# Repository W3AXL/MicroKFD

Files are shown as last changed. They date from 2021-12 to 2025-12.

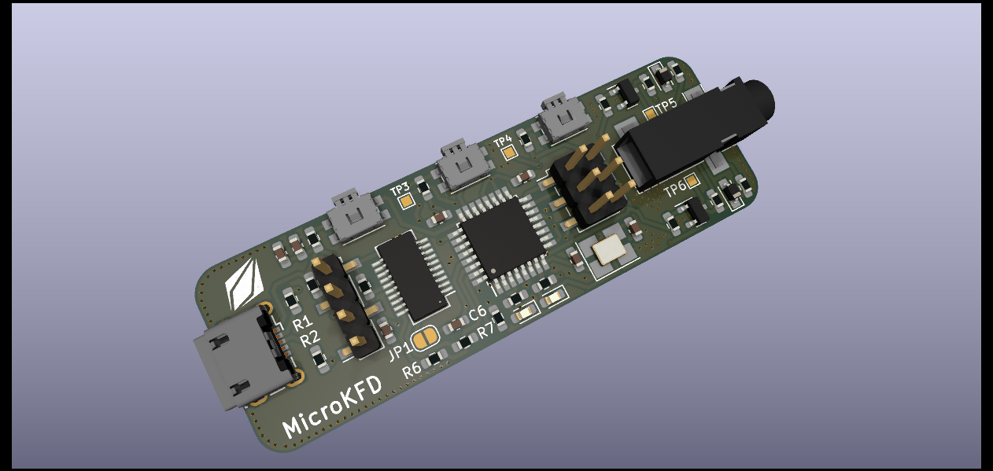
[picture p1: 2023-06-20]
board-revE.png

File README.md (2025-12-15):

The KFDMicro (formerly known as MicroKFD) is a small, compact KFD keyfill device for P25 two-way radios.

Schematics and board layout are available in this repo. The official boards (which provide a small kickback to the original developers) can be purchased at:
https://store.w3axl.com/collections/kfd-keyloading

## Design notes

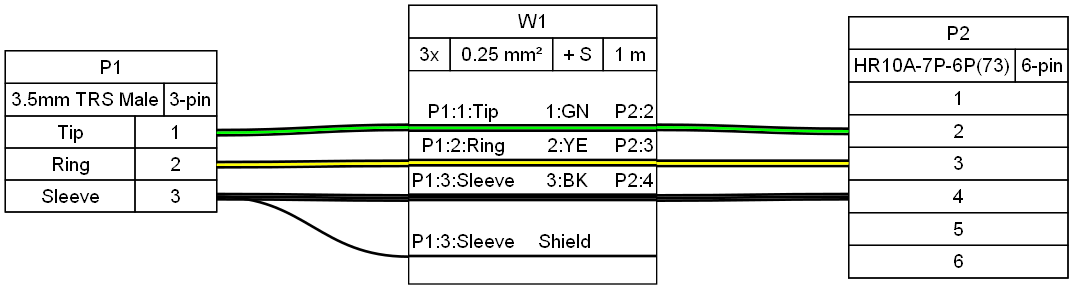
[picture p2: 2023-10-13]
cables/hirose-adapter.png

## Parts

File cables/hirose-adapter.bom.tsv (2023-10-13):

Id | Description | Qty | Unit | Designators
1 | Cable, 3 x 0.25 mm² shielded | 1 | m | W1
2 | Connector, 3.5mm TRS Male, 3 pins | 1 |  | P1
3 | Connector, HR10A-7P-6P(73), 6 pins | 1 |  | P2

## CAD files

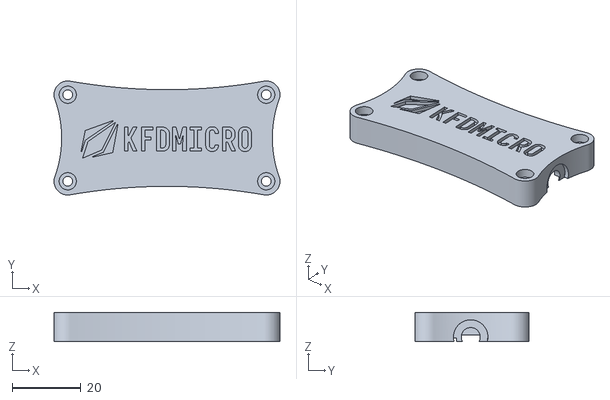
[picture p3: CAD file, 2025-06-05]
enclosure/enclosure-top-revB.stl
65.6 x 33.1 x 8.50

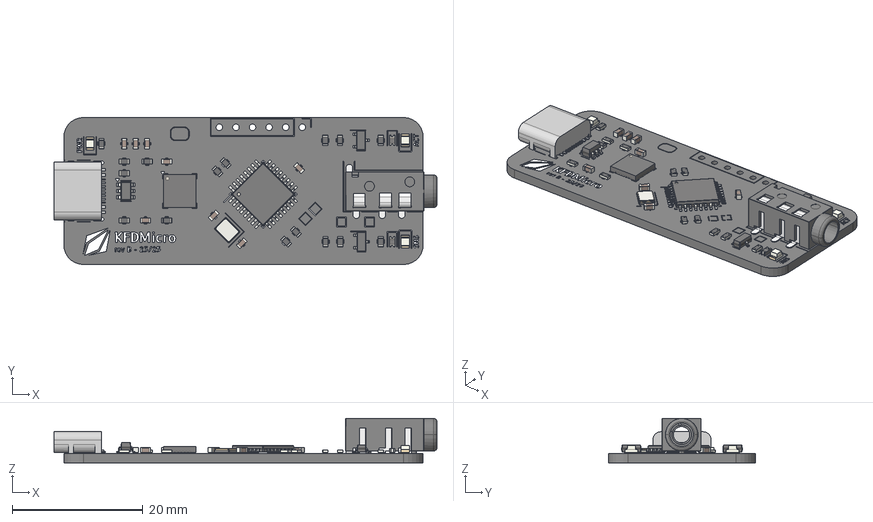
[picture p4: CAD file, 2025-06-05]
microkfd-revB.step
58.6 x 22.5 x 6.92 mm
LED_0805_2012Metric x 3
SOT-23 x 2
C_0603_1608Metric x 8
R_0603_1608Metric x 15
Crystal_SMD_3225-4Pin_3.2x2.5mm
TQFP-32_7x7mm_P0.8mm
HRO TYPE-C-31-M-12
QFN-28-1EP_5x5mm_P0.5mm_EP3.35x3.35mm
D_0603_1608Metric x 2
PJ320A
PJ320D-Pin x 3
PJ320D-Pin-B
SOT-23-6
Fuse_0603_1608Metric
microkfd_silkscreen
microkfd_PCB

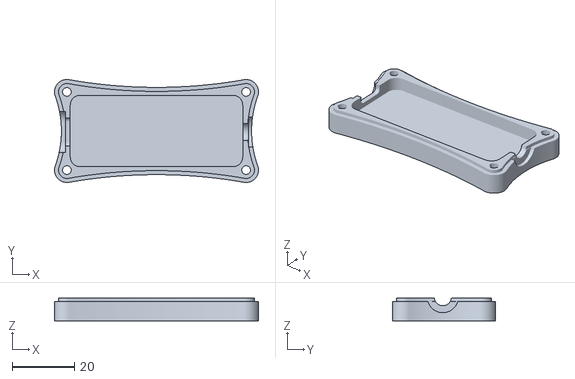
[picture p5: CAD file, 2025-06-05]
enclosure/enclosure-bottom-revB.stl
65.6 x 33.1 x 7.25

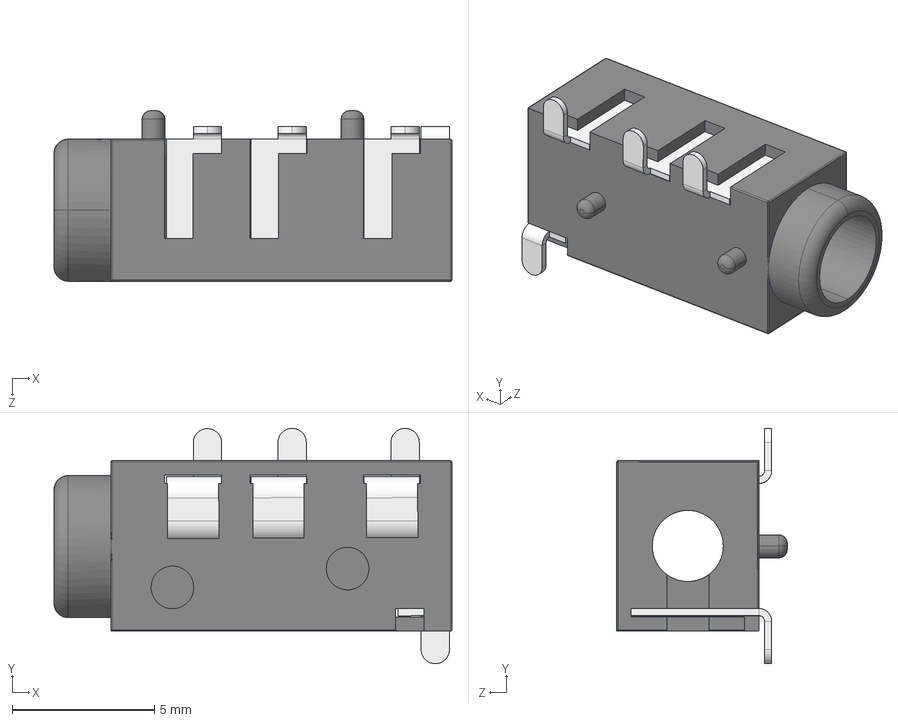
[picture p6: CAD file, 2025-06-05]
PJ320D.STEP
14.0 x 8.28 x 6.00 mm
PJ320A
PJ320D-Pin x 3
PJ320D-Pin-B

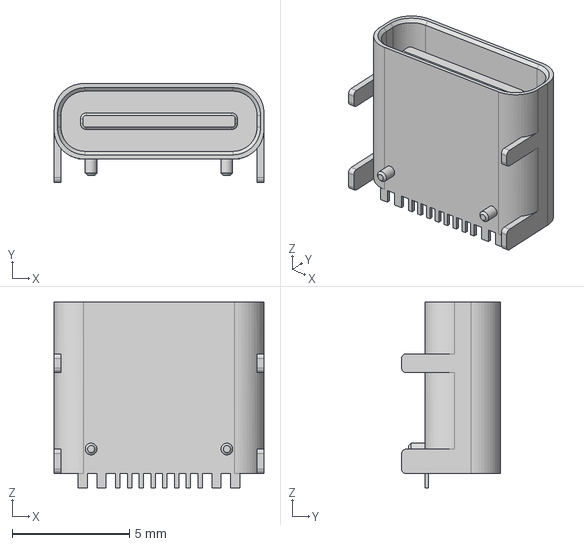
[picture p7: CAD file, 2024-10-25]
HRO TYPE-C-31-M-12.step
8.94 x 4.21 x 7.90 mm

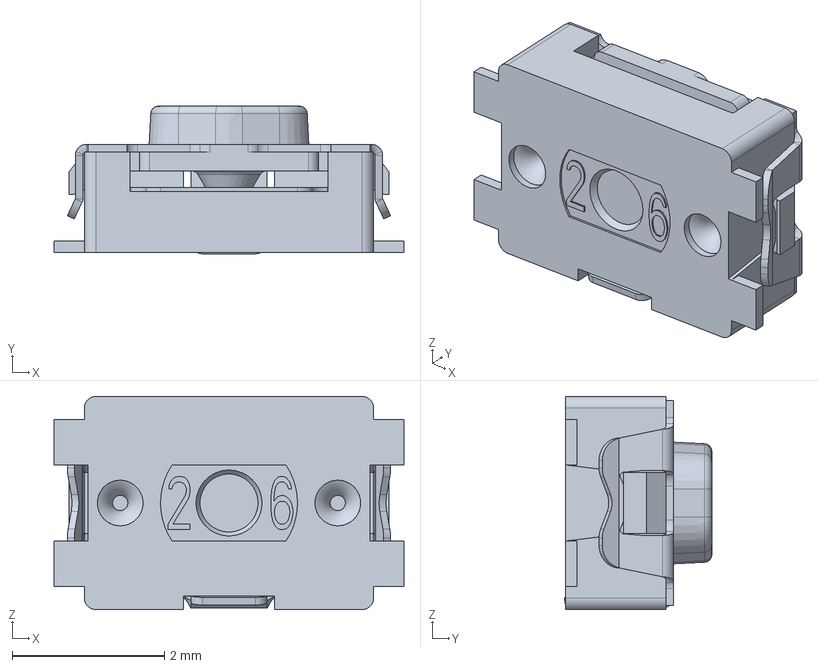
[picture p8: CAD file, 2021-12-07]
KMR211GLFS.stp
4.60 x 1.94 x 2.80 mm

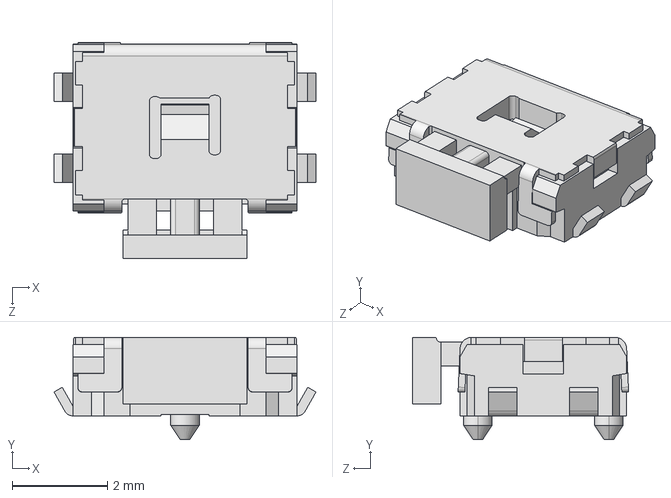
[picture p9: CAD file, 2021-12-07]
EVQPU-MD-02K.STEP
5.50 x 2.15 x 4.54 mm

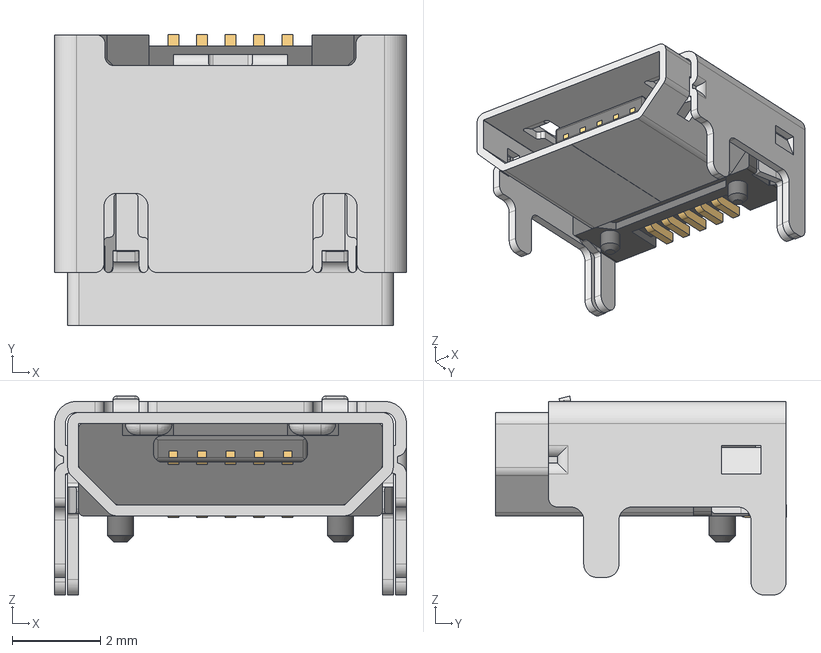
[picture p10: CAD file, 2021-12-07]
629105150521_Download_STP_629105150521_rev1.stp
8.00 x 6.60 x 4.52 mm
629105150521_Pin1 x 4
629105150521_Housing
629105150521_Pin2
629105150521_Shielding
629105150521_Shielding2

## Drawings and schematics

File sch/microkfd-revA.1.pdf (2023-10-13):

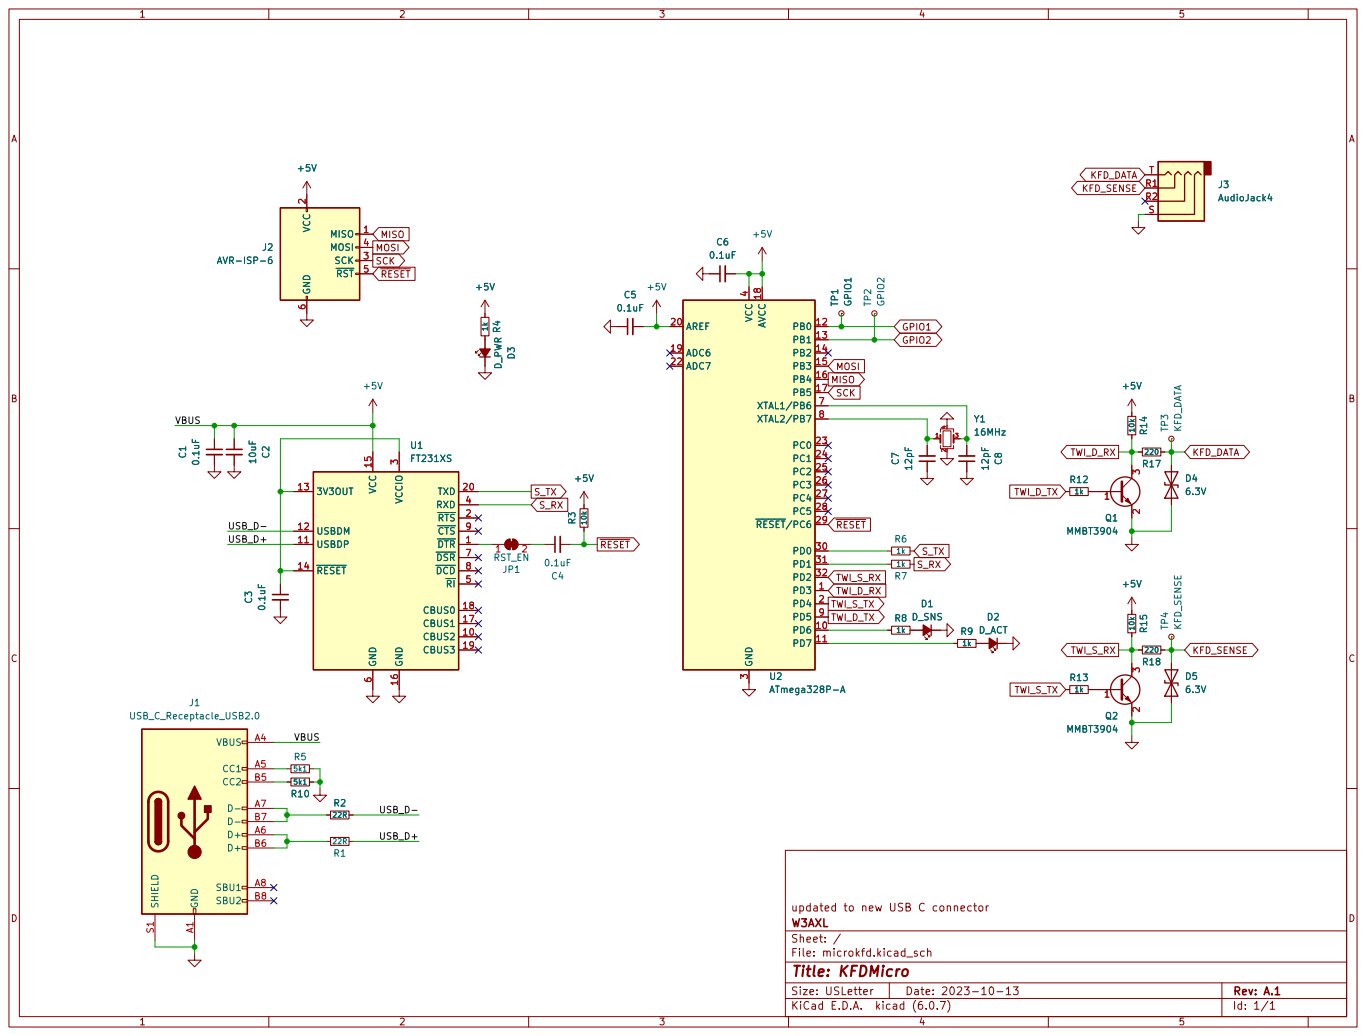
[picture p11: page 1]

2 SCK 3 MOSI 4 ~{RST} 5 GND

2 3 Q1 MMBT3904 PD3 1 PD6 10 PD7 11 PB0 12 PB1 13 PB2 14 PB3 15 PB4 16 PB5 17 AVCC 18 ADC6 19 PD4 2 AREF 20 ADC7 22 PC0 23 PC1 24 PC2 25 PC3 26 PC4 27 PC5 28 ~{RESET}/PC629 GND

updated to new USB C connector
File: microkfd.kicad_sch Sheet: / W3AXL

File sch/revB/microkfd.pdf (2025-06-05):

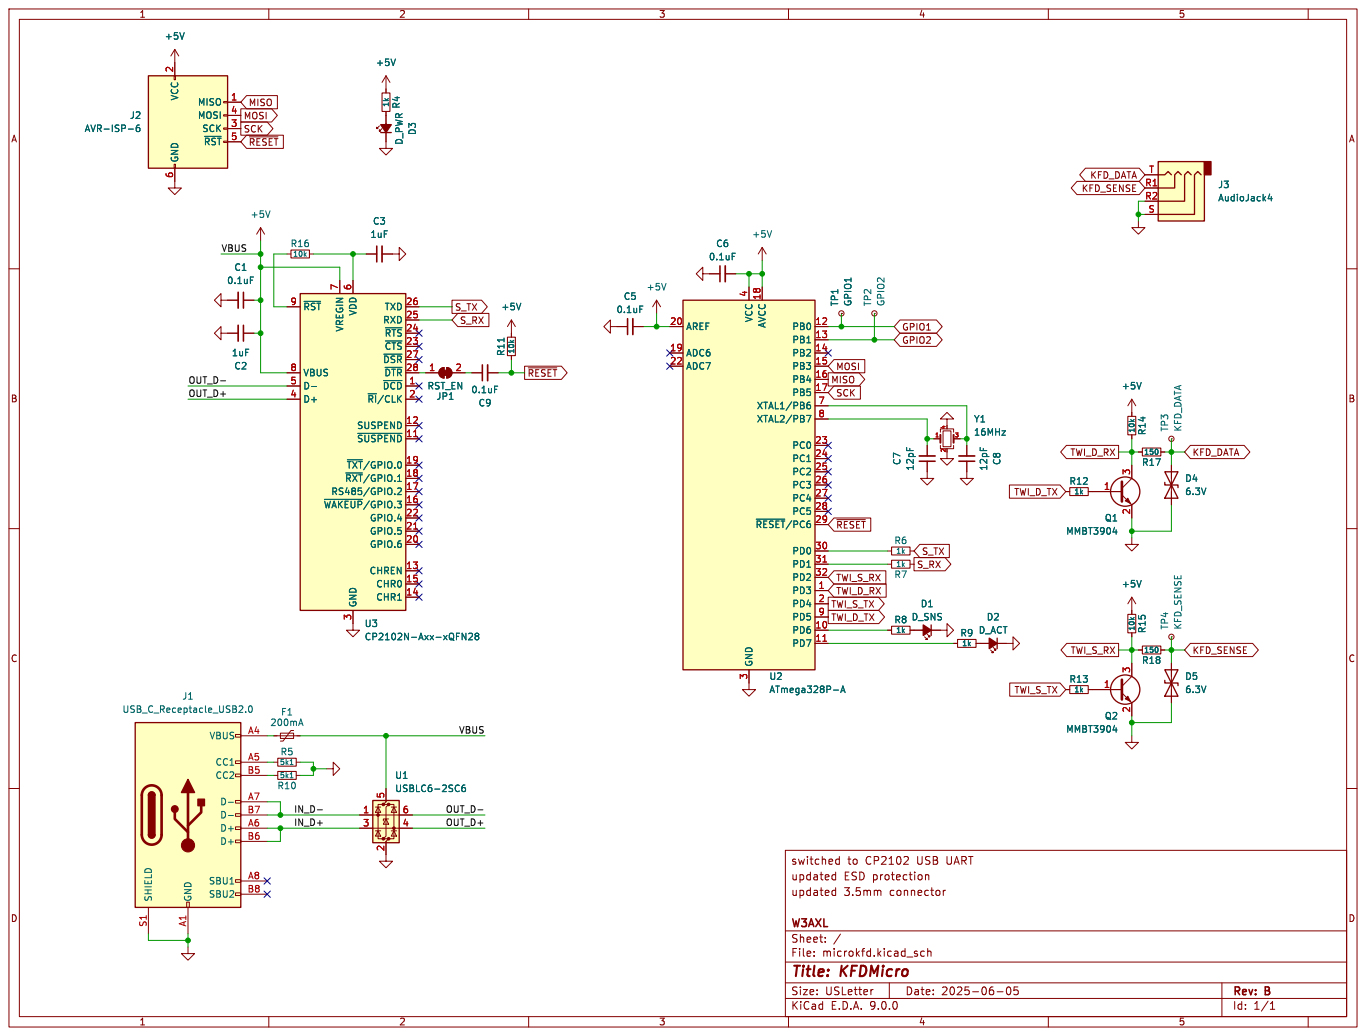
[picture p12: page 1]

6 MISO 1 MOSI 4 SCK 3 ~{RST}5 +5V 1k R4 C3

6 MISO 1 MOSI 4 SCK 3 ~{RST}5

3 TXD 26 RXD 25 ~{RTS} 24 ~{CTS} 23 ~{DSR} 27 ~{DTR} 28 ~{DCD}1 ~{RI}/CLK2 SUSPEND 12 ~{SUSPEND}11 ~{TXT}/GPIO.019 ~{RXT}/GPIO.118 RS485/GPIO.2 17 ~{WAKEUP}/GPIO.316 GPIO.4 22 GPIO.5 21 GPIO.6 20 CHREN 13 CHR0 15 CHR1 14 U3 CP2102N-Axx-xQFN28 D2 D_ACT D3 D_PWR

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

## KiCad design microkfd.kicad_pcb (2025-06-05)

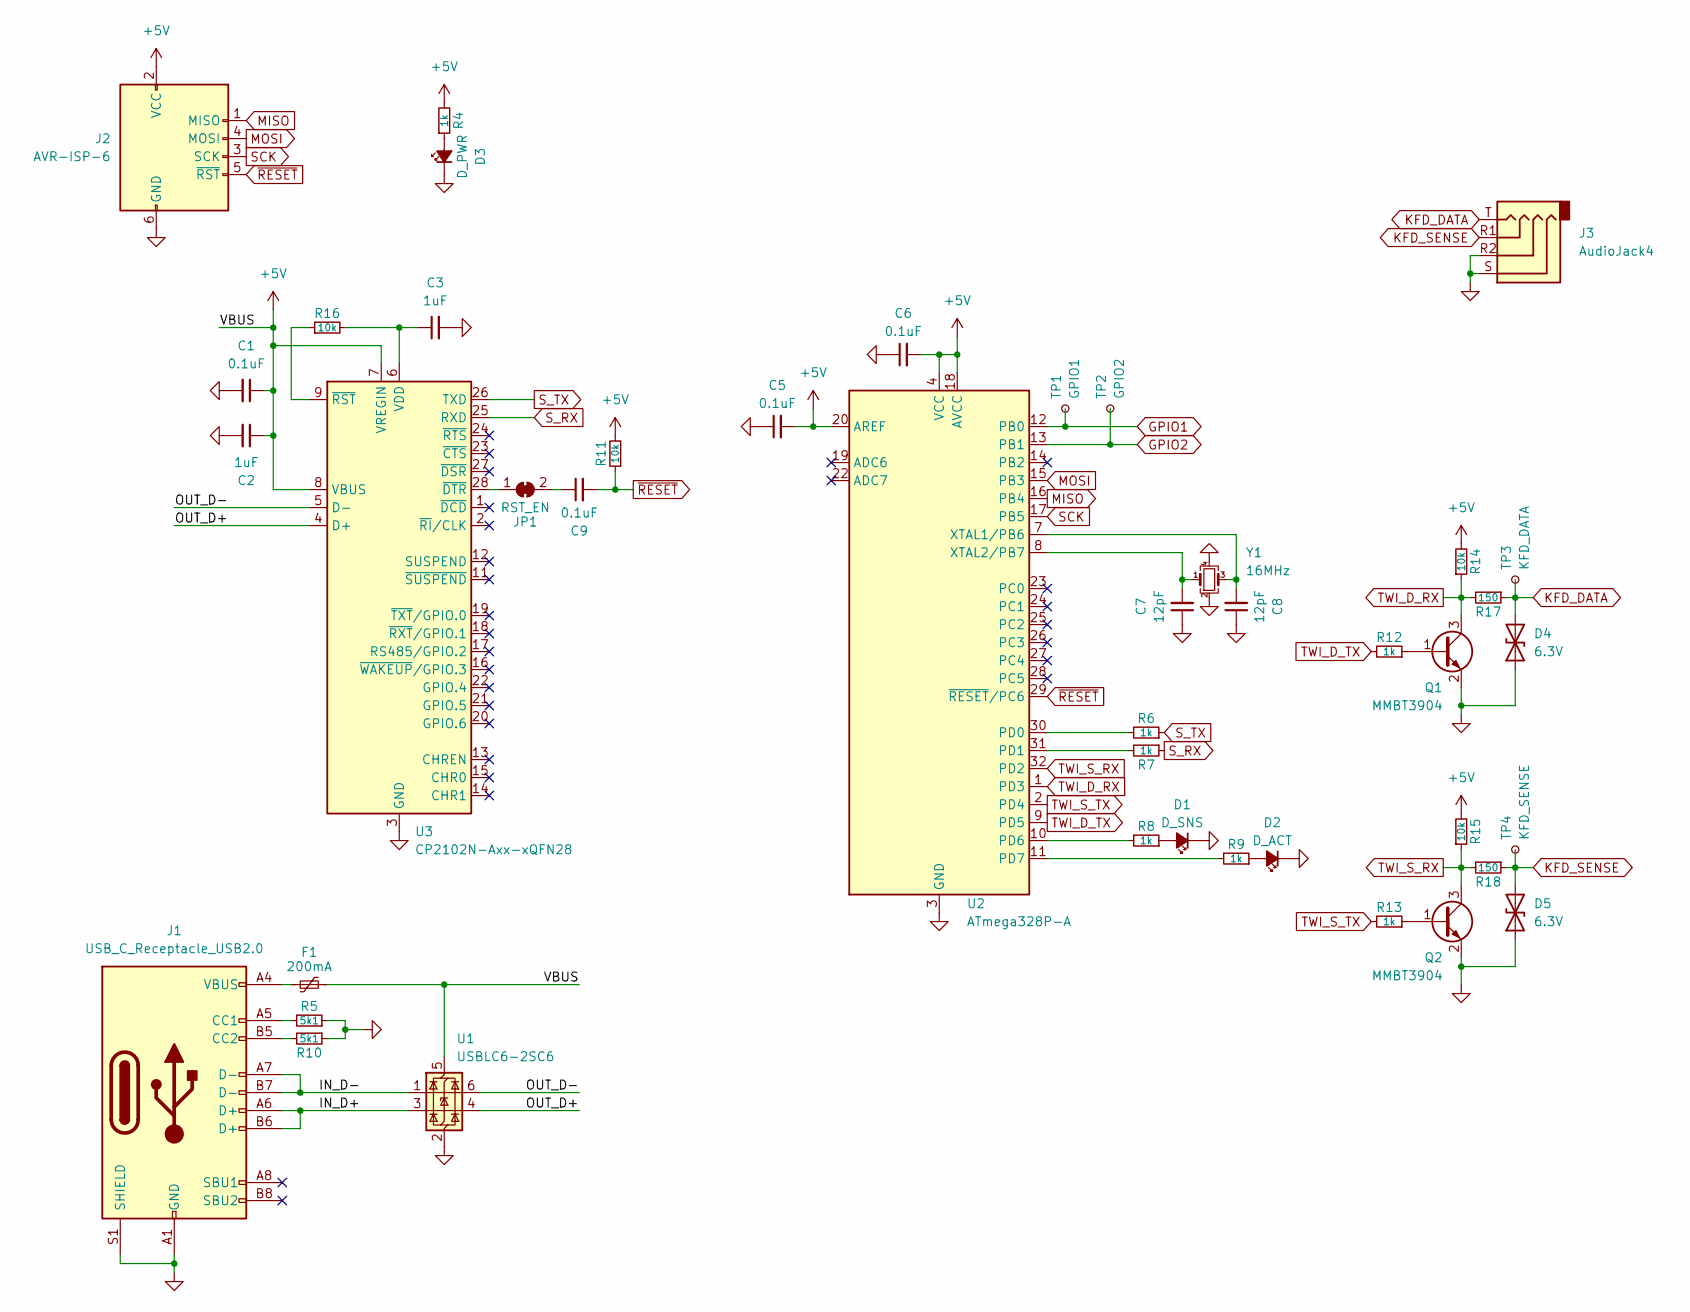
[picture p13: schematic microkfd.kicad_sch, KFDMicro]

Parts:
C1, C5, C6, C9: 0.1uF; C_0603_1608Metric; LCSC C28233
C2, C3: 1uF; C_0603_1608Metric; LCSC C15850
C7, C8: 12pF; C_0603_1608Metric; LCSC C1792
D1: D_SNS; LED_0805_2012Metric; LCSC C84256
D2: D_ACT; LED_0805_2012Metric; LCSC C84256
D3: D_PWR; LED_0805_2012Metric; LCSC C2297
D4, D5: 6.3V; D_0603_1608Metric; LCSC C85200
F1: 200mA; Fuse_0603_1608Metric
J1: USB_C_Receptacle_USB2.0; USB_C_Receptacle_HRO_TYPE-C-31-M-12; LCSC C2874595
J2: AVR-ISP-6; PinHeader_1x06_P2.54mm_Vertical
J3: AudioJack4; Jack_3.5mm_KoreanHropartsElec_PJ-320D-4A_Horizontal; LCSC C707216
JP1: RST_EN; SolderJumper-2_P1.3mm_Bridged_RoundedPad1.0x1.5mm
Q1, Q2: MMBT3904; SOT-23; LCSC C20526
R4, R6, R7, R8, R9, R12, R13: 1k; R_0603_1608Metric; LCSC C17513
R5, R10: 5k1; R_0603_1608Metric; LCSC C27834
R11, R14, R15, R16: 10k; R_0603_1608Metric; LCSC C17414
R17, R18: 150; R_0603_1608Metric; LCSC C17557
TP1: GPIO1; TestPoint_Pad_1.0x1.0mm
TP2: GPIO2; TestPoint_Pad_1.0x1.0mm
TP3: KFD_DATA; TestPoint_Pad_1.0x1.0mm
TP4: KFD_SENSE; TestPoint_Pad_1.0x1.0mm
U1: USBLC6-2SC6; SOT-23-6
U2: ATmega328P-A; TQFP-32_7x7mm_P0.8mm; LCSC C14877
U3: CP2102N-Axx-xQFN28; QFN-28-1EP_5x5mm_P0.5mm_EP3.35x3.35mm
Y1: 16MHz; Crystal_SMD_3225-4Pin_3.2x2.5mm; LCSC C2149025

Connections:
+5V: C1.1, C2.1, C5.2, C6.2, F1.2, J2.2 (VCC), R4.2, R11.2, R14.2, R15.2, U1.5 (VBUS), U2.4 (VCC), U2.6 (VCC), U2.18 (AVCC), U2.20 (AREF), U3.7 (VREGIN), U3.8 (VBUS)
/IN_D+: J1.A6 (D+), J1.B6 (D+), U1.3 (I/O2)
/IN_D-: J1.A7 (D-), J1.B7 (D-), U1.1 (I/O1)
/OUT_D+: U1.4 (I/O2), U3.4 (D+)
/OUT_D-: U1.6 (I/O1), U3.5 (D-)
GND: C1.2, C2.2, C3.2, C5.1, C6.1, C7.1, C8.1, D1.1 (K), D2.1 (K), D3.1 (K), D4.1 (A1), D5.1 (A1), J1.A1 (GND), J1.A12 (GND), J1.B1 (GND), J1.B12 (GND), J1.S1 (SHIELD), J2.6 (GND), J3.R2, J3.S, Q1.2 (E), Q2.2 (E), R5.1, R10.1, U1.2 (GND), U2.3 (GND), U2.5 (GND), U2.21 (GND), U3.3 (GND), U3.29 (GND), Y1.2, Y1.4
GPIO1: TP1.1, U2.12 (PB0)
GPIO2: TP2.1, U2.13 (PB1)
KFD_DATA: D4.2 (A2), J3.T, R17.1, TP3.1
KFD_SENSE: D5.2 (A2), J3.R1, R18.1, TP4.1
MISO: J2.1 (MISO), U2.16 (PB4)
MOSI: J2.4 (MOSI), U2.15 (PB3)
unnamed: D1.2 (A), R8.1
unnamed: D2.2 (A), R9.1
unnamed: D3.2 (A), R4.1
unnamed: F1.1, J1.A4 (VBUS), J1.A9 (VBUS), J1.B4 (VBUS), J1.B9 (VBUS)
unnamed: J1.A5 (CC1), R5.2
unnamed: J1.B5 (CC2), R10.2
unnamed: JP1.1 (A), U3.28 (~DTR)
unnamed: C9.1, JP1.2 (B)
unnamed: Q1.1 (B), R12.1
unnamed: Q2.1 (B), R13.1
unnamed: R6.2, U2.30 (PD0)
unnamed: R7.2, U2.31 (PD1)
unnamed: R8.2, U2.10 (PD6)
unnamed: R9.2, U2.11 (PD7)
unnamed: C8.2, U2.7 (XTAL1/PB6), Y1.3
unnamed: C7.2, U2.8 (XTAL2/PB7), Y1.1
unnamed: C3.1, R16.2, U3.6 (VDD)
unnamed: R16.1, U3.9 (~RST)
SCK: J2.3 (SCK), U2.17 (PB5)
S_RX: R7.1, U3.25 (RXD)
S_TX: R6.1, U3.26 (TXD)
TWI_D_RX: Q1.3 (C), R14.1, R17.2, U2.1 (PD3)
TWI_D_TX: R12.2, U2.9 (PD5)
TWI_S_RX: Q2.3 (C), R15.1, R18.2, U2.32 (PD2)
TWI_S_TX: R13.2, U2.2 (PD4)
~RESET: C9.2, J2.5 (~RST), R11.1, U2.29 (~RESET/PC6)

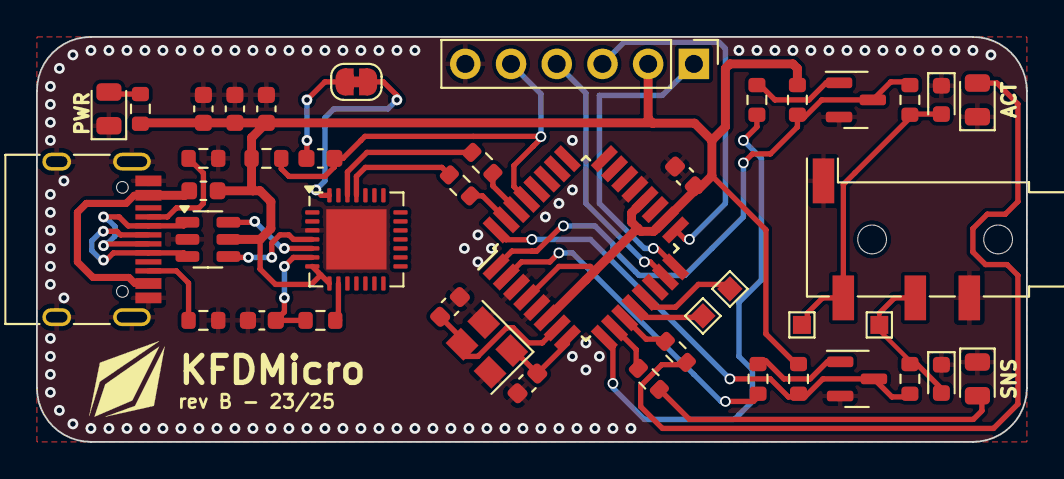
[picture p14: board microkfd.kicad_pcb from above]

Board: 2 copper layers, 55.0 x 22.5 mm, 43 parts (0 on the bottom side), 38 nets.

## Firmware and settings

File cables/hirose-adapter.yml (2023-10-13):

connectors:
  P1:
    pincount: 3
    pinlabels: [Tip, Ring, Sleeve]
    type: 3.5mm TRS Male
  P2:
    pincount: 6
    type: HR10A-7P-6P(73)
  
cables:
  W1:
    wirecount: 3
    length: 1
    shield: true
    gauge: 0.25 mm2
    colors: [GN, YE, BK]

connections:
  - 
    - P1: 3
    - W1: s
  -
    - P1: [1-3]
    - W1: [1-3]
    - P2: [2-4]

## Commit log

2021-12-06 Initial project commit
    [microkfd.kicad_pcb, microkfd.sch]
2021-12-07 rev A design done
    [629105150521_Download_STP_629105150521_rev1.stp, CUI_DEVICES_SJ-3523-SMT-TR.step, EVQPU-MD-02K.STEP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]
2021-12-07 added gerbers
2022-01-08 cleanups and updates
    - switched to Kicad 6.0
    - removed Kicad 5.x files
    - switched to 32u4RC due to availability
    [microkfd-B_Cu.gbr, microkfd-B_Mask.gbr, microkfd-B_Paste.gbr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]
2022-01-08 finalized rev B
    switched MOSFETs due to parts availability, regenerated gerbers
    [microkfd-B_Cu.gbr, microkfd-B_Mask.gbr, microkfd-B_Paste.gbr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]
2022-01-19 revC updates
    fixed missing data input line (now runs to PC2 interrupt pin)
    [microkfd-B_Cu.gbr, microkfd-B_Mask.gbr, microkfd-B_Paste.gbr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]
2022-04-09 rev D: fixed pin mappings
    changed pin mappings to be closer to original KFDShield, added correct sense and data lines
    [microkfd-B_Cu.gbr, microkfd-B_Mask.gbr, microkfd-B_Paste.gbr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]
2022-05-26 added logo to PCB
    [microkfd.kicad_pcb]
2022-05-26 updated gerbers for logo change
    [microkfd-B_Cu.gbr, microkfd-B_Mask.gbr, microkfd-B_Paste.gbr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]
2023-01-18 revision E - atmega328p redesign
    [microkfd-B_Cu.gbr, microkfd-B_Mask.gbr, microkfd-B_Paste.gbr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]
2023-05-29 finalized 328p design
    [microkfd-B_Cu.gbr, microkfd-B_Mask.gbr, microkfd-B_Paste.gbr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]
2023-05-29 updated gerbers
    [microkfd-B_Cu.gbr, microkfd-B_Mask.gbr, microkfd-B_Paste.gbr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]
2023-06-20 final rev F DFM updates
    [microkfd-B_Cu.gbr, microkfd-B_Mask.gbr, microkfd-B_Paste.gbr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]
2023-06-20 updated DFM docs
    [microkfd-bom.csv, microkfd.csv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]
2023-06-20 fixed pos
    [microkfd-top-pos.csv]
2023-10-02 updated to gitignore
    [microkfd-bom.csv, microkfd.kicad_pcb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]
2023-10-13 updated to revA.1
    [hirose-adapter.bom.tsv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]
2024-10-25 dfm updates 2024
    [HRO TYPE-C-31-M-12.step, microkfd.kicad_pcb, microkfd.kicad_sch]
2025-06-05 rev B hardware updates
    [microkfd-B_Cu.gbr, microkfd-B_Mask.gbr, microkfd-B_Paste.gbr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]
2025-06-05 fixed audio connector PN
    [microkfd.kicad_pcb]
2025-06-05 fixed audio connector model
    [CUI_DEVICES_SJ-3523-SMT-TR.step, PJ320D.STEP, microkfd-revB.step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]
2025-06-05 final revB updates for dev mfr run
    [enclosure-bottom-revB.stl, enclosure-top-revB.stl, microkfd.kicad_pcb]
